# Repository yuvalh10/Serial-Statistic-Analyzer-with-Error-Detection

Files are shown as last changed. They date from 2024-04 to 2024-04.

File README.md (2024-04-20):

# Serial-Statistic-Analyzer-with-Error-Detection

In this VHDL project, our objective is to design a system that receives blocks of data via serial communication and performs statistical analysis, 
including calculations for maximum, minimum, average, and median values. 
Additionally, the system will detect and quantify errors in the communication for each received block of data. 
We'll incorporate pre-existing component files to support the implementation.

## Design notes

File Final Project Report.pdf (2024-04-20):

המחלקה להנדסת התקנים לוגיים חשמל ואלקטרוניקה מתוכנתים, 31551

## דו"ח פרויקט סוף קורס סטטיסטיקה על נתוני בלוקים בתקשורת טורית

מוגש ע"י: יובל המר, 209158518 מוגש ע"י: עידו בן הרוש, 316439116

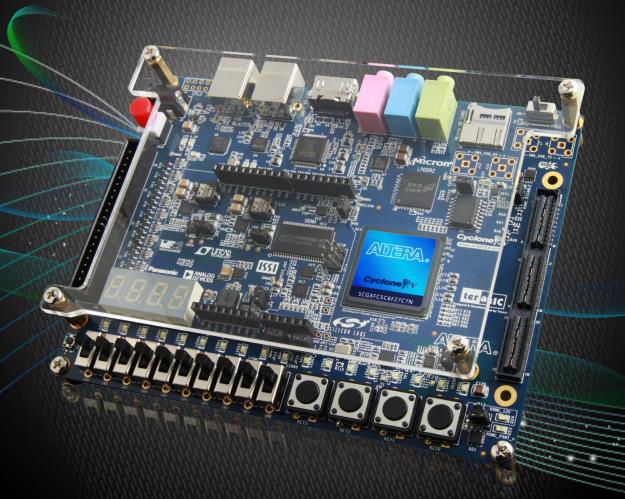
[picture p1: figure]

בהנחיית: ד"ר פאדל טריף

תאריך: 25/03/24

## תוכן עניינים

מבוא: 3 |
פירוט דרישות המערכת4 | :
תיאור מצבי המערכת: 5 |
תהליך תכנון הרכיבים: 6 |
6 | :Serial to Parallel רכיב
תיאור הרכיב: 6 |
סימולציה לרכיב6 | :
דיאגרמת RTL: 8 |
9 | :Main Controller רכיב
תיאור הרכיב: 9 |
דיאגרמת RTL: 10 |
רמה עליונה – Level Top: 11 |
תיאור הרכיב: 11 |
סימולציה לרכיב11 | :
דיאגרמת RTL: 16 |
הקצאת פינים ודו"ח קומפילציה: 17 |
סרטון הדגמת המערכת: 18 |
19 | :SIGNAL-TAP
19 | :SIGNAL-TAP הגדרת
תוצאות אנליזת TAP-SIGNAL20 | :
מצב Ⅰ20 | :
מצב Ⅱ20 | :
מצב Ⅲ22 | :
מצב Ⅳ22 | :
קומפילציה לאחר TAP-SIGNAL23 | :
נספחים: 24 |

## מבוא:

בפרויקט זה, עלינו לתכנן מערכת הקולטת בלוקי נתונים בתקשורת טורית ומחשבת עליהם סטטיסטיקה – מקסימום, מינימום, ממוצע וחציון. בנוסף, המערכת תחשב את מספר השגיאות שהיו בתקשורת הנ"ל עבור כל בלוק נתונים שהתקבל. להלן סכימת בלוקים כללית של המערכת שעלינו לממש:

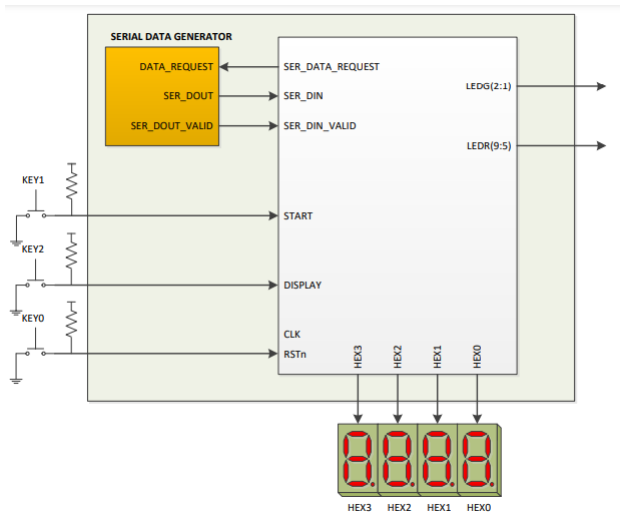
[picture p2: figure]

הבלוק הכתום ידמה את משדר הנתונים הסינכרוני, אשר קיבלנו כרכיב נתון ויהווה חלק מהקושחה הכללית.

## פירוט דרישות המערכת:

.1 המערכת תופעל משעון יחיד של MHz .50 .2 כפתור Reset – עובד בנמוך. .3 המערכת תתעורר במצב Idle. .4 לחיצה ראשונה על הלחצן Start תגרום לבלוק Parallel to Serial להתחיל להוציא בלוק נתונים וכן תעביר את המערכת ממצב Idle למצב קליטה. .5 גודל בלוק נתונים יהיה תמיד 64 נתונים. .6 כל נתון מורכב מ8- סיביות )מספר חיובי בין 0 ל255-( + סיבית זוגיות )סה"כ 9 סיביות לנתון(. .7 כל נתון משודר בצורה טורית. .8 בסיום קליטת 64 הנתונים, המערכת תעבור בצורה אוטומטית למצב חישוב. .9 על המערכת לחשב את הערכים הבאים:

- הערך המקסימלי מתוך 64 הערכים.
- הערך המינימלי מתוך 64 הערכים.
- הערך הממוצע של 64 ערכים.
- החציון של 64 הערכים.
- מספר השגיאות שהגיעו מהמשדר. .10 בחישובים בהם התוצאה יכולה להיות מספר לא שלם, יש לעגל כלפי מטה. .11 בסיום החישוב, המערכת תעבור למצב הצגת הנתונים ותדליק את 2LEDG. .12 במצב הצגת הנתונים יוצג ע"ג התצוגה הערך המקסימלי. לחיצה על Display תגרום להצגת הערך המינימלי, לחיצה נוספת תציג את הממוצע, לחיצה נוספת את החציון ולחיצה נוספת את מספר השגיאות שהיו. לחיצה נוספת תציג מחדש את הערך המקסימלי וחוזר חלילה. .13 לחיצה על Start במצב הצגת הנתונים תחזיר את המערכת למצב Idle. 2LEDG יכבה בשלב זה. .14 לחיצה נוספת על Start אחרי שהמערכת חזרה למצב Idle, תתחיל את התהליך מחדש. .15 1LEDG ידלוק תמיד.
.16 הלדים 9LEDR5-LEDR יסמנו איזו תוצאה מוצגת כרגע על תצוגת ה-Segment.7-.17 כאשר המערכת לא נמצאת במצב הצגת הנתונים, תצוגת ה-Segment7- תהיה כבויה.

## תיאור מצבי המערכת :

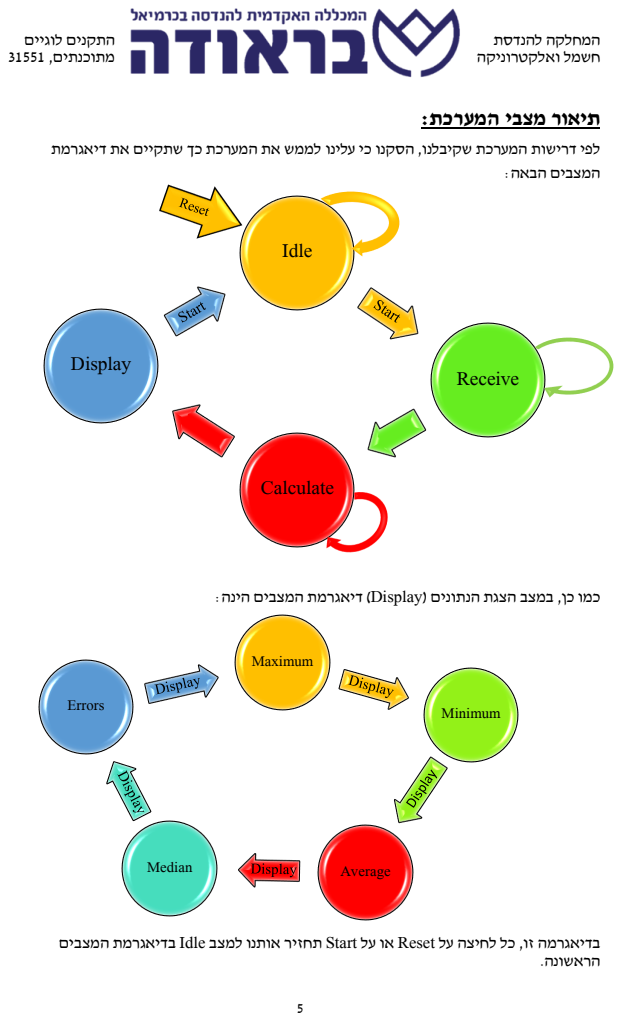
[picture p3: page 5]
המצבים הבאה:; הראשונה.; Idle; Receive; Calculate; Display; Maximum; Minimum; Median; Average; Errors

לפי דרישות המערכת שקיבלנו, הסקנו כי עלינו לממש את המערכת כך שתקיים את דיאגרמת

כמו כן, במצב הצגת הנתונים )Display )דיאגרמת המצבים הינה:

בדיאגרמה זו, כל לחיצה על Reset או על Start תחזיר אותנו למצב Idle בדיאגרמת המצבים

## תהליך תכנון הרכיבים:

בחלק זה נפרט על הרכיבים אשר מימשנו באופן עצמאי בלבד. :Serial to Parallel רכיב
תיאור הרכיב:
רכיב זה ממיר את המידע המתקבל בתקשורת טורית למידע מקבילי אשר עליו ניתן לבצע חישובים וסטטיסטיקות.
בעזרת אוגר הזזה הרכיב קולט את הנתונים הטוריים וממיר אותם למקביליים. כמו כן, הרכיב בודק את תקינות הנתונים בעזרת סיבית הזוגיות שהתקבלה. הנתונים המקביליים מוכנים לעיבוד כאשר מוצא VALID DOUT PAR יהיה '1'.

תיאור סכמתי של הבלוק:

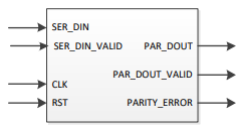
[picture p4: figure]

להלן פירוט הפורטים והמשתנים הגנריים של רכיב זה:

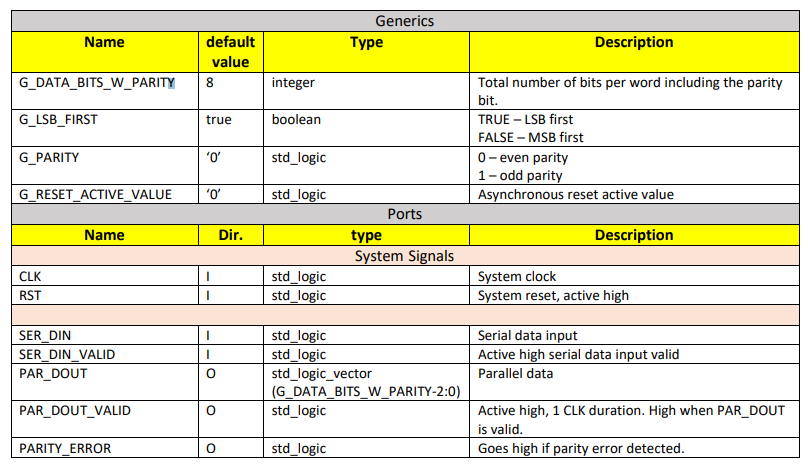
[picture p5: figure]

להלן מימוש רכיב זה: Component Parallel To Serial (https://1drv.ms/u/s!AnQ2VsqUAy-QhfRh5Kb36aPP4mpiXg?e=3cs5c9)

סימולציה לרכיב:
למען בדיקת תקינות רכיב זה, יצרנו קובץ TB וקובץ DO: Serial To Parallel Testbench (https://1drv.ms/u/s!AnQ2VsqUAy-QhfRgW-OdxmMuWwhARA?e=QSDXcm) Serial To Parallel DO (https://1drv.ms/u/s!AnQ2VsqUAy-QhfRXE4jgjZjNv7iw0g?e=mt8uhH)

1 | להלן תוצאות הסימולציה לאחר הרצת ה-TB בתוכנת ה-ModelSim( כניסת LSB
)

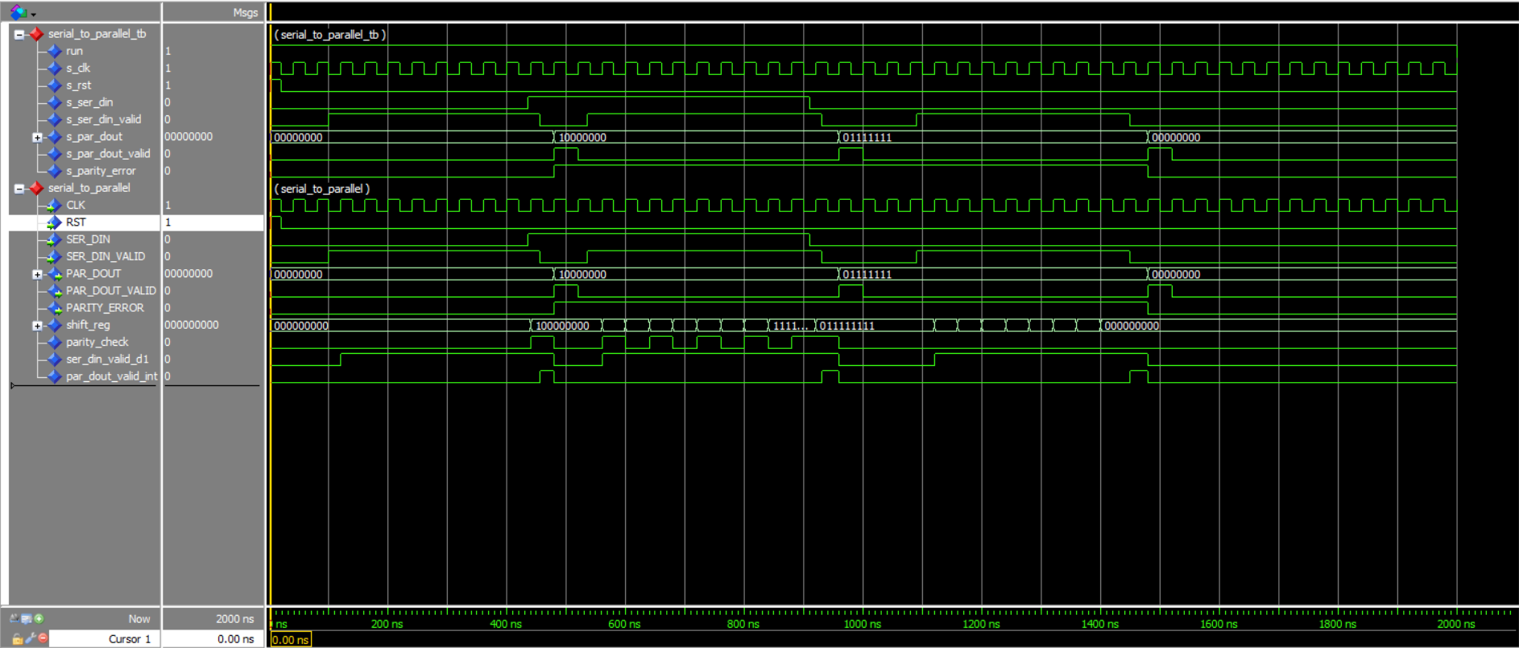
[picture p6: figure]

מצב Ⅰ, כניסת הנתון 11111111 עם סיבית זוגיות 1 )11111111-1(:

ניתן לראות כי הכניסה VALID DIN SER שווה ל-'1' עבור 9 מחזורי שעון מלאים. )ספירת עליית שעון(.
הכניסה DIN SER אשר אחראית על כניסת המידע עולה ל-'1' בעליית שעון הבאה, בעוד שהאות VALID DIN SER יורד ל-'0' למשך 2 מחזורי שעון ועולה חזרה ל-'1'. לאחר מכן, המערכת תתחיל להכניס את המידע לאוגר (Register Shift (כך שסיבית ה-LSB תיכנס ראשונה.
האוגר יתחיל להתמלא במידע ויהיה מוכן ליציאה רק כאשר int_valid_dout_par יהיה '1'. במצב זה הנתונים באוגר יועברו לאות המוצא DOUT_PAR וה-ERROR_PARITY יתעדכן ל-'1'. כלומר הייתה טעות בבדיקת הנתונים.

מצב Ⅱ, כניסת הנתון 00000000 עם סיבית זוגיות 0 )00000000-0(:

הכניסה VALID DIN SER שווה ל-'1' עבור 10 מחזורי שעון מלאים. )ספירת עליית שעון( הכניסה DIN SER נשארת ב-'0' קבוע. המערכת תתחיל להכניס מידע לאוגר כך סיבית ה-LSB תיכנס ראשונה. האוגר יתחיל להתמלא במידע ויהיה מוכן ליציאה רק כאשר int_valid_dout_par יהיה '1'. במצב זה הנתונים באוגר יועברו לאות המוצא DOUT_PAR וה-ERROR_PARITY יתעדכן ל-'0'. כלומר לא הייתה שגיאה בקליטת הנתונים.

1
עבור כניסת MSB תוצאות הסימולציה יהיו זהות פרט לאופן כניסת המידע לאוגר ההזזה )הכנסה לימין לשמאל(

דיאגרמת RTL:

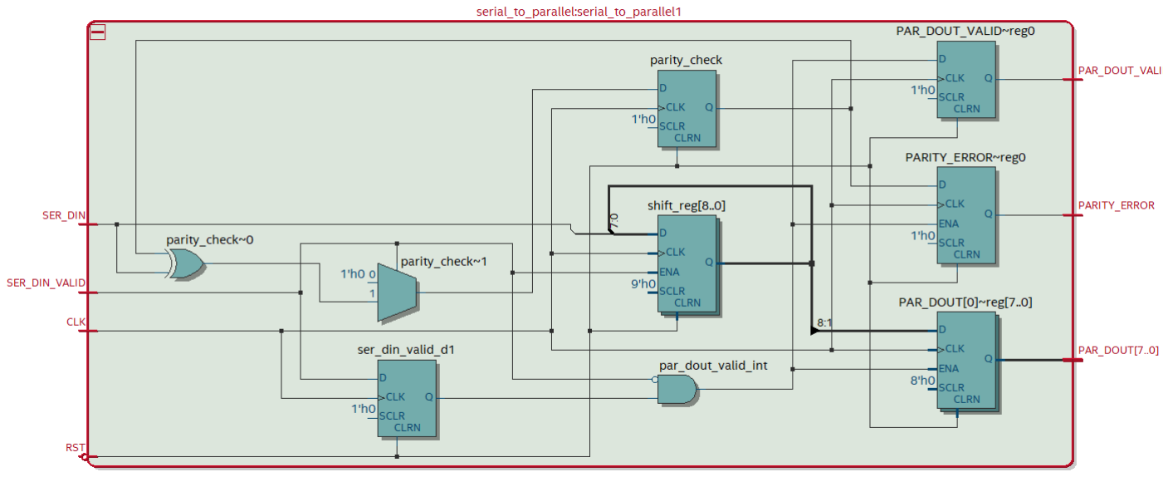
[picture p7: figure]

Main Controller רכיב ² :
תיאור הרכיב:
רכיב זה אחראי על מעבר בין מכונת מצבים שתוארה קודם לכן. הרכיב אחראי ליצירת אות לבקשת המידע (Request Data(. כמו כן, הרכיב אחראי למיון הנתונים לפי מיון בועות (sort Bubble (וחישוב הסטטיסטיקות להצגה. בנוסף, במוצא הרכיב נקבל את האותות הבאים להצגת הנתונים: RESULT – הסטטיסטיקה המוצגת )מקסימום, מינימום, ממוצע, חציון או שגיאות(. READY_RESULT – משמעותו שהנתונים מוכנים לתצוגה למשתמש. TYPE_RESULT – אחראי על תצוגת סוג הסטטיסטיקה המוצגת )מחובר ללדים האדומים ברמה העליונה(

תיאור סכמתי של הבלוק:

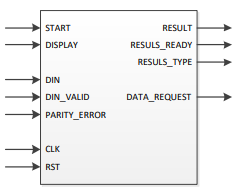
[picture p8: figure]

להלן פירוט הפורטים והמשתנים הגנריים של רכיב זה:

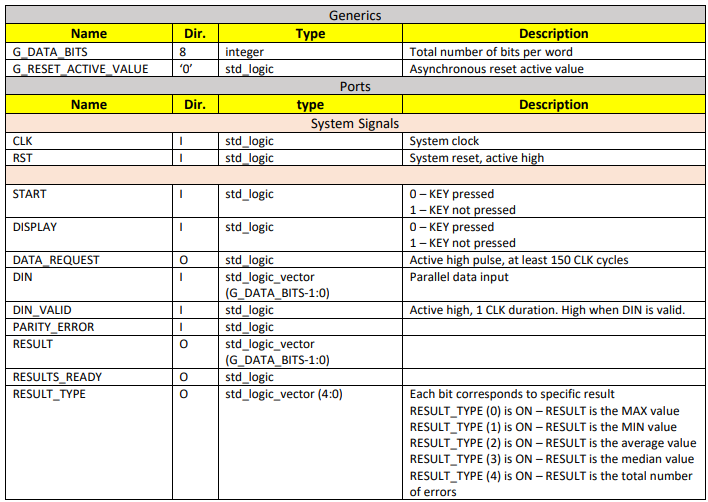
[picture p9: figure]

להלן מימוש רכיב זה: Component Controller Main (https://1drv.ms/u/s!AnQ2VsqUAy-QhfRi5hOepWznz8q90g?e=I6kWVU)

2
בלוק זה ייבדק במהלך ביצוע הסימולציה הכללית הנתונה לרמה העליונה.

3: | דיאגרמת RTL

3

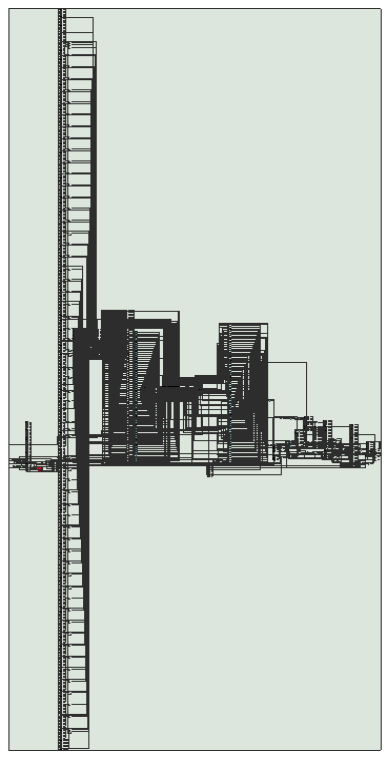
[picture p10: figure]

במהלך בדיקת מכונת המצבים ברכיב, זה נוכחנו לגלות כי היא לא מומשה כמצופה, אלא בעזרת רכיבים חומרתיים בלבד. ייתכן כי עובדה זו גלומה בכך שהמערכת עשתה אופטימיזציה והצליחה למצוא דרך לממש את מכונת המצבים )הנחשבת בזבזנית( בעזרת ר כיבים פשוטים יותר.

רמה עליונה – Level Top:
תיאור הרכיב:
לאחר שמימשנו את הבקר הראשי (Controller Main (ואת ממיר הנתונים (Parallel To Serial (תוך שימוש בשאר הרכיבים שנתונים לנו בפרויקט זה, בנינו את הרכיב calc_Statistics הנחשב כישות רמה עליונה (entity level Top (ומתכלל בין כלל הרכיבים אל ה-"עולם החיצון."

כמו כן, ישות זו מקשרת בין הפורטים הרלוונטיים בין כלל הרכיבים על מנת לקבל את התוצאה הרצויה.

להלן פירוט הפורטים של רכיב זה:

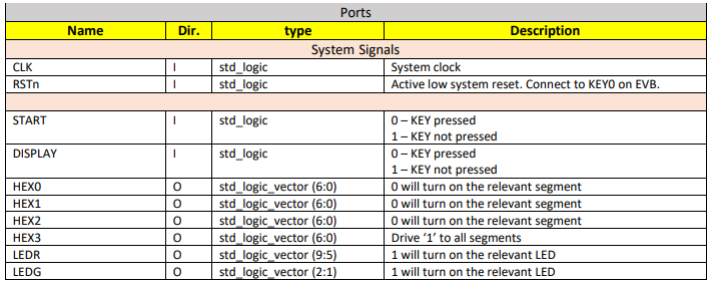
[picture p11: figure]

להלן מימוש רכיב זה: Level Top calc Statistics (https://1drv.ms/u/s!AnQ2VsqUAy-QhfRfBacUU58DXrMCdQ?e=kP4u3r)

סימולציה לרכיב:
למען בדיקת תקינות רכיב זה, קיבלנו קובץ TB ייעודי ומספר וקבצי DO: Statistics calc Testbench (https://1drv.ms/u/s!AnQ2VsqUAy-QhfReSqyLuajTX-yCDA?e=2TuPq3)
DO components all Compile (https://1drv.ms/u/s!AnQ2VsqUAy-QhfRdWf5gRi4n26bK4Q?e=eJn6oB) – קובץ קומפילציה לכלל הרכיבים במערכת. DO all Run (https://1drv.ms/u/s!AnQ2VsqUAy-QhfRbAB2FfqaXUPI_kg?e=yptIfv) – קובץ הרצת הסימולציה.

להלן תוצאות הסימולציה לאחר הרצת ה-TB בתוכנת ה- ModelSim) Controller Main(:

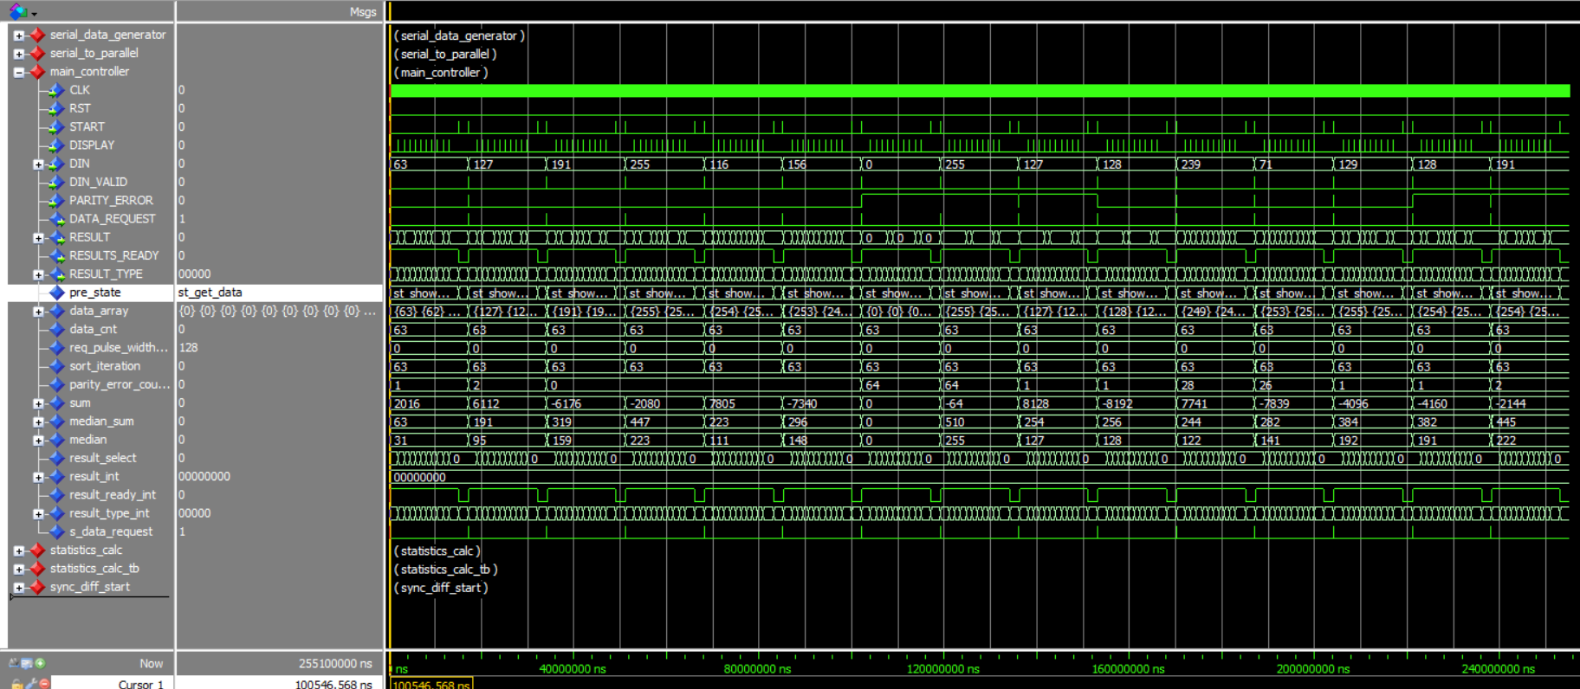
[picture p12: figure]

נתרכז בקבלת הנתון הראשון:

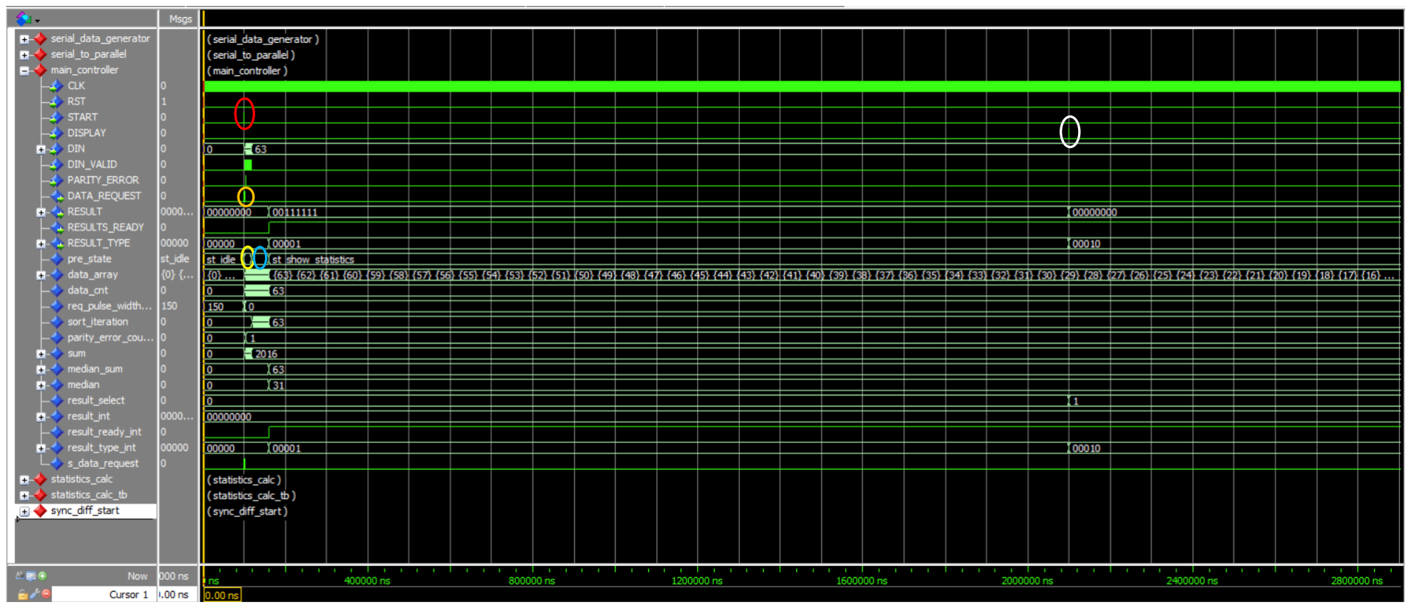
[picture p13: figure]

ניתן לראות כי בתחילת הרצת הסימולציה המערכת מתעוררת במצב Idle כנדרש. לאחר מכן, לאחר לחיצה על Start( מסומן באדום( תיתן פקודה לאות REQUEST DATA לקבל '1' )מסומן בכתום( והמערכת עוברת למצב data Get( מסומן בצהוב(. לאחר מכן נעבור למצב של מיון הנתונים )מסומן בכחול(.
רק לאחר שאות המוצא READY RESULTS עולה ל1- אנו נכנסים למצב של הצגת הנתונים כאשר הנתון הראשון שאנו מציגים הינו הערך המקסימלי. לחיצה על לחצן ה-Display( מסומן בלבן( תעביר אותנו להצגת הערך המינימלי כנדרש.

להלן תוצאות הסימולציה לאחר הרצת ה-TB בתוכנת ה- ModelSim) calc Statistics(:

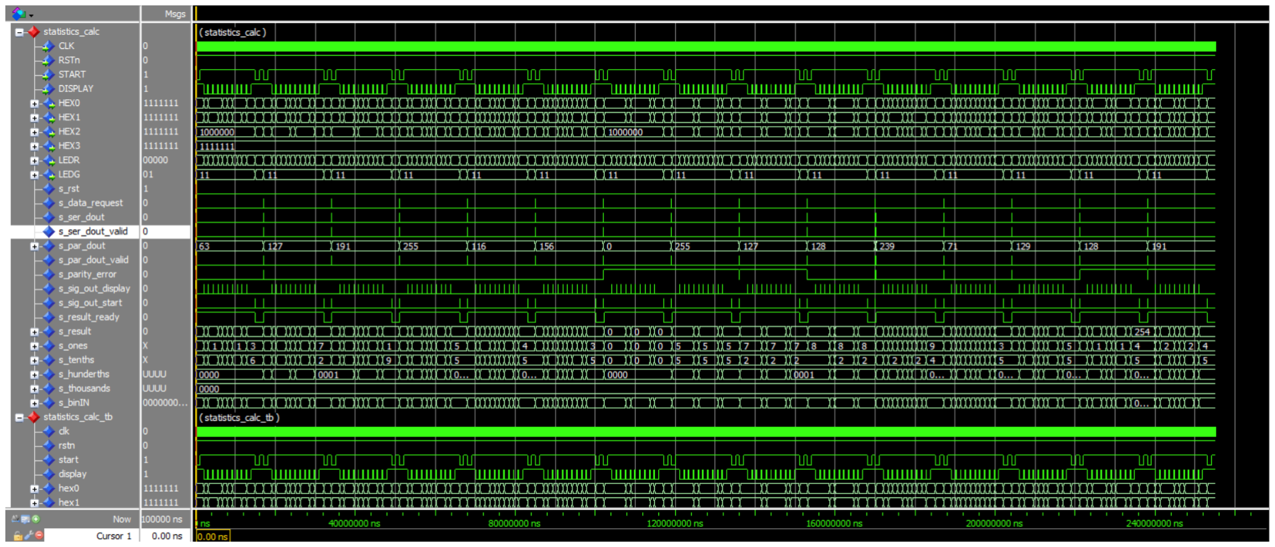
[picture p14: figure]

נתרכז בקבלת הנתון הראשון:

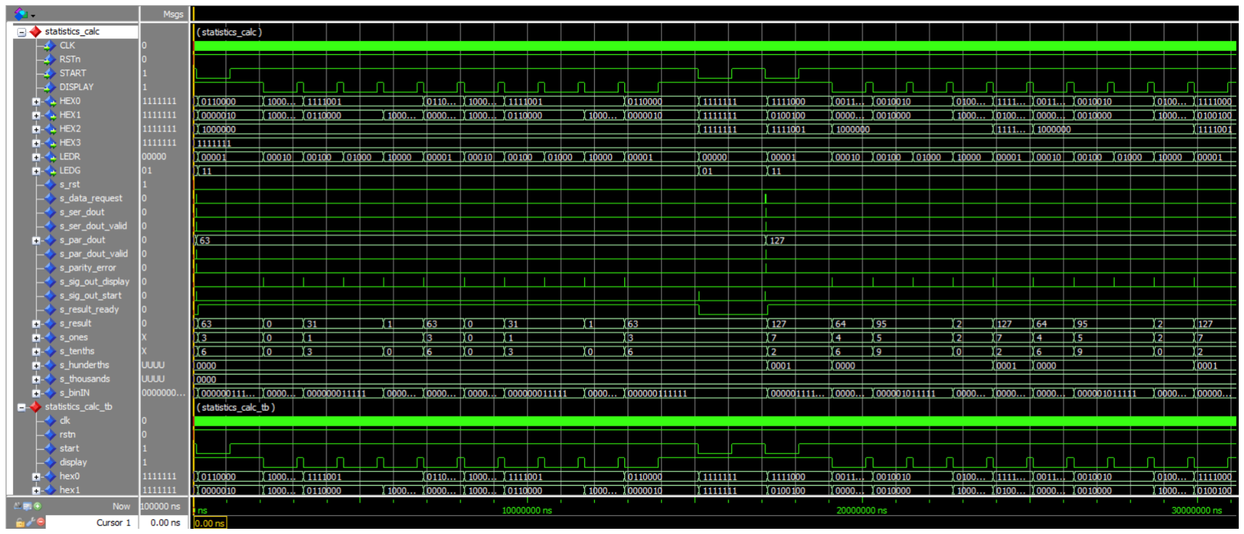
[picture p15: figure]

ניתן לראות כי כאשר לחצן ה-Start עובד בנמוך המערכת מתחילה את פעולתה. בנוסף, עבור לחיצה על לחצן ה-Display( עובד בנמוך( ניתן לראות המעברים בין הסטטיסטיקות שחושבו על הנתונים.
את המעברים הנ"ל ניתן לראות בשינוי התוצאות בסיגנל result_s ובשינוי ה-LEDR שדולק בהתאם לסטטיסטיקה המוצגת.
כמו כן, לחיצה נוספת על Start תוריד את הסיגנל ready_result_s ל-'0' ובכך תינתן פקודה לעבור להציג את הסטטיסטיקות על הנתון הבא. הצגת הנתונים הבאה תתאפשר רק לאחר שהסיגנל ready_result_s עלה ל'1'.

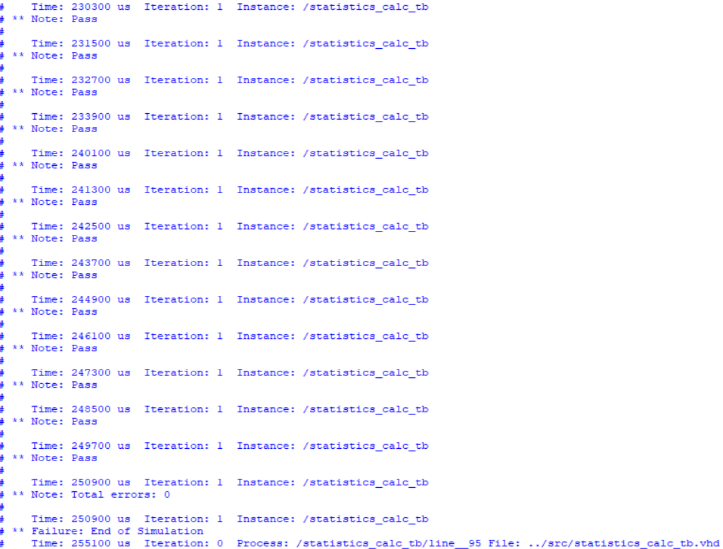
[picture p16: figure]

בנוסף, הופק עבורנו דו"ח מה-TB בו השתמשנו על מנת לזהות שגיאות בפעולת המערכת:

ניתן לראות כי המערכת שבנינו עברה את כל הבדיקות הנדרשות ב-TB זה וסימולציית המערכת הושלמה בהצלחה.

דיאגרמת RTL:

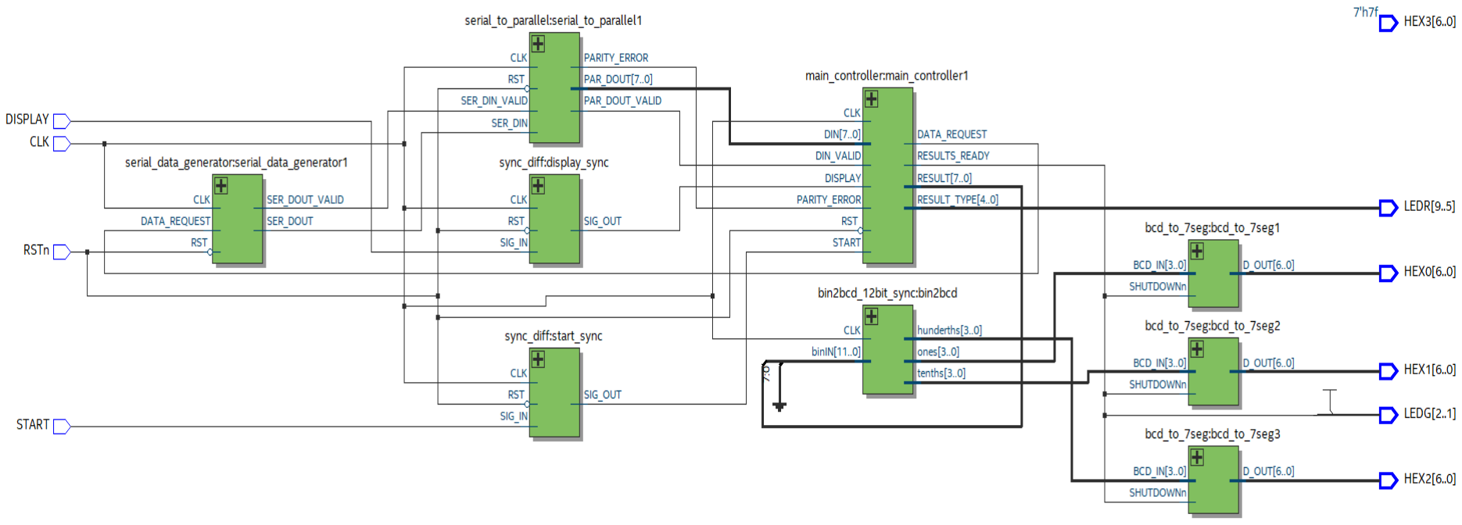
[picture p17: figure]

## הקצאת פינים ודו"ח קומפילציה :

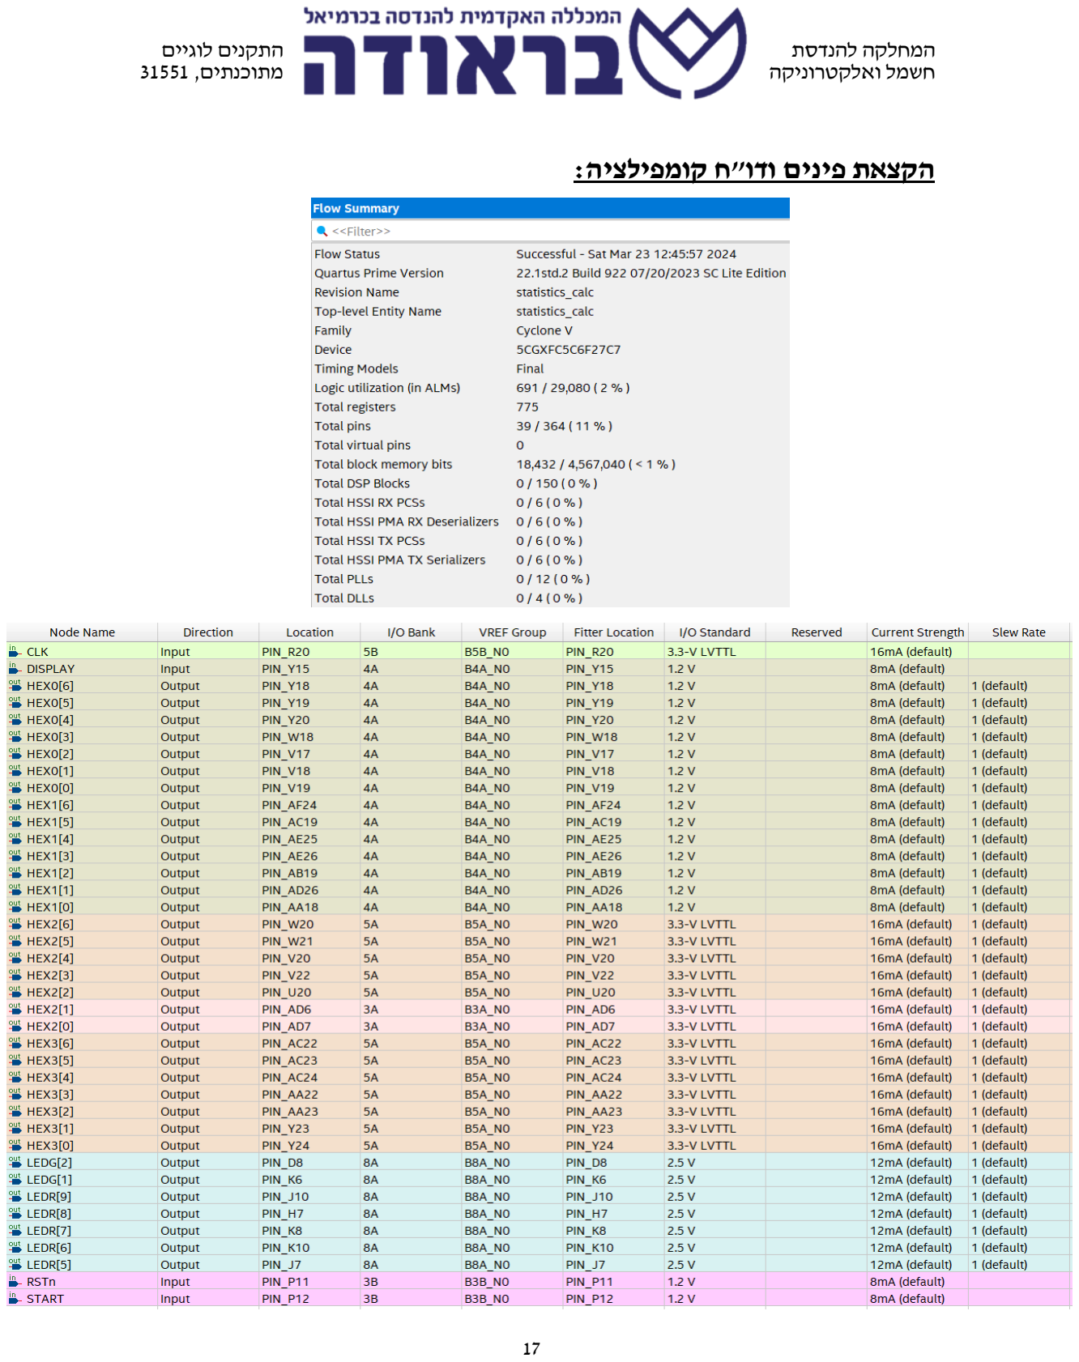
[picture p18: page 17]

## סרטון הדגמת המערכת:

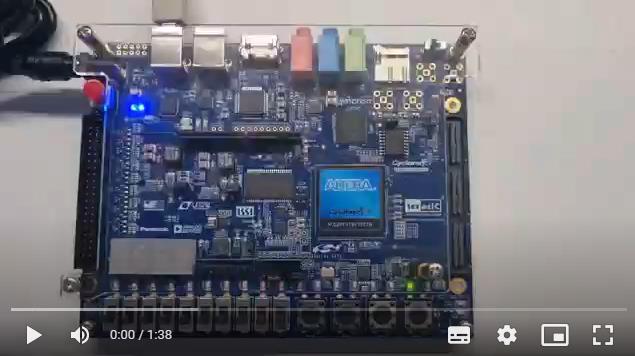
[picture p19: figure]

## :SIGNAL-TAP

:SIGNAL-TAP הגדרת
במטרה להשתמש ב-Tap-Signal יצרנו קובץ חדש מסוג STP והגדרנו את ה-Tap-Signal באופן הבא:

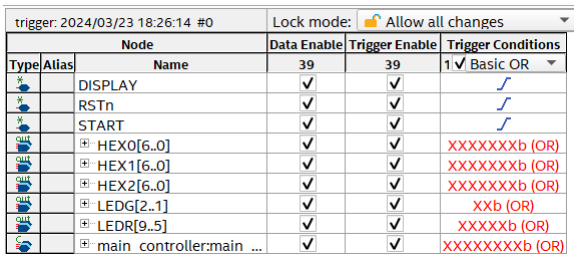
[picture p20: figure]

בכדי לראות בתוכנת הקוורטוס שהמערכת עובדת כראוי, הוספנו את לחצני ה- Start ,Reset ,Display מכיוון שהם משפיעים על מעבר המערכת ממצב למצב וביכולתו של המשתמש להיות בבקרה על כך. נוסיף גם את תצוגות ה-Segment7- בכדי לראות את השינויים שבתצוגה. נוסיף גם את LEDG ו-LEDR בכדי לראות את השינויים המתבצעים בהם במעבר ממצב אחד למשנהו.
בנוסף, נרצה לוודא שהתוצאות המוצגות ברכיב אכן נכונות, לשם כך נוסיף את אות ה-RESULT. בכדי לראות את השינויים בין מצב אחד לאחר, נדרוש שהאנליזה תתרחש בעליית הלחצנים שהגדרנו תוך לוגיקת OR בין הדרבונים הנ"ל.

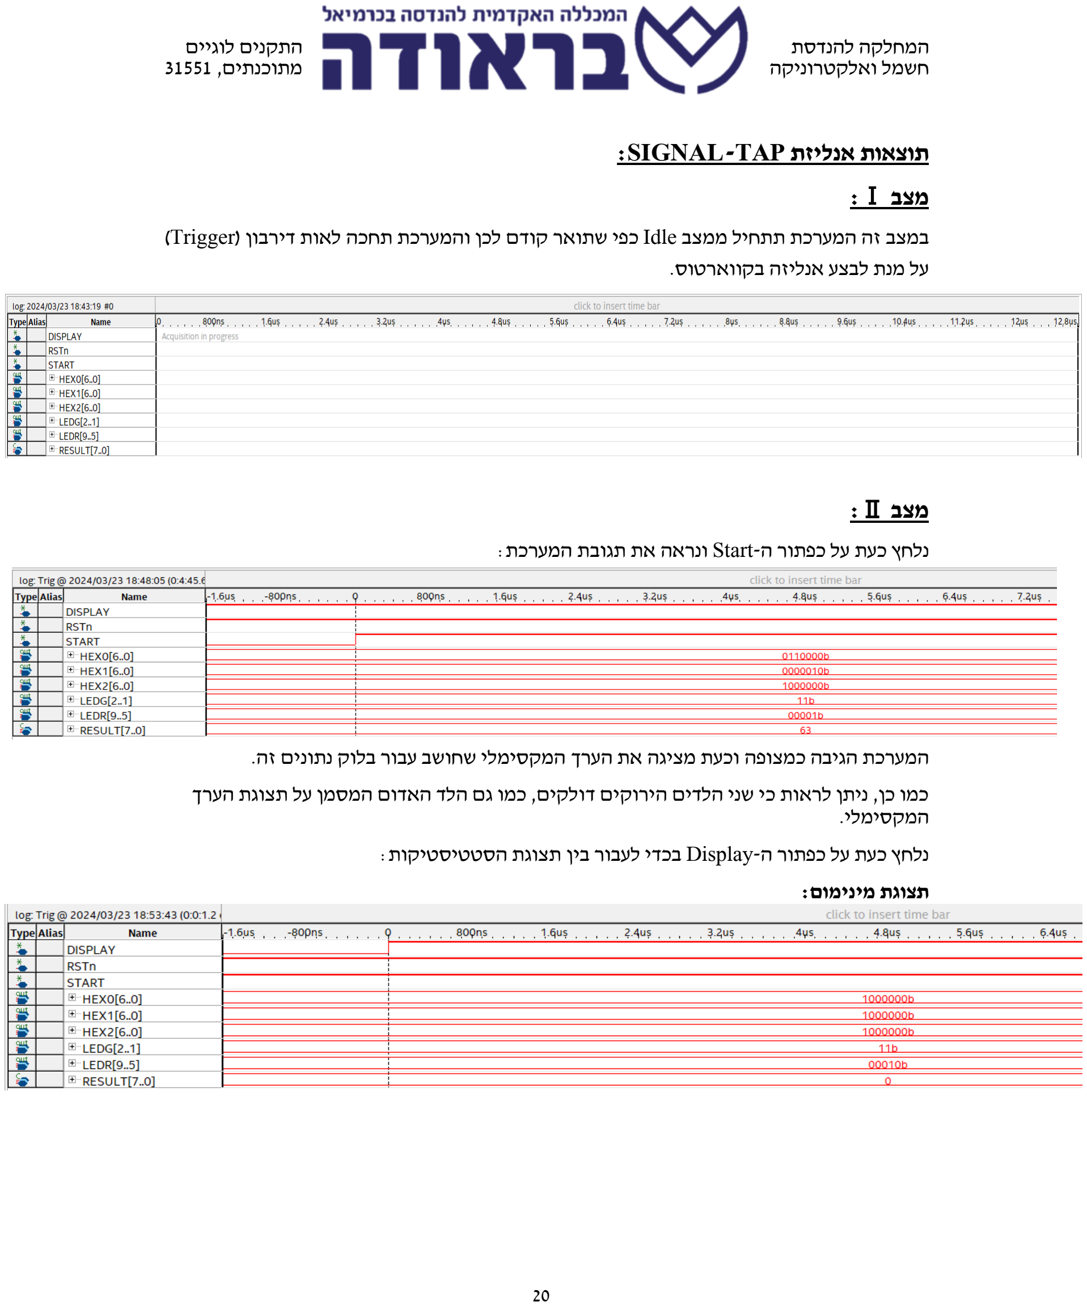
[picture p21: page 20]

תוצאות אנליזת TAP-SIGNAL:
מצב Ⅰ:

במצב זה המערכת תתחיל ממצב Idle כפי שתואר קודם לכן והמערכת תחכה לאות דירבון (Trigger( על מנת לבצע אנליזה בקווארטוס.

מצב Ⅱ:

נלחץ כעת על כפתור ה-Start ונראה את תגובת המערכת:

המערכת הגיבה כמצופה וכעת מציגה את הערך המקסימלי שחושב עבור בלוק נתונים זה. כמו כן, ניתן לראות כי שני הלדים הירוקים דולקים, כמו גם הלד האדום המסמן על תצוגת הערך המקסימלי.
נלחץ כעת על כפתור ה-Display בכדי לעבור בין תצוגת הסטטיסטיקות: תצוגת מינימום:

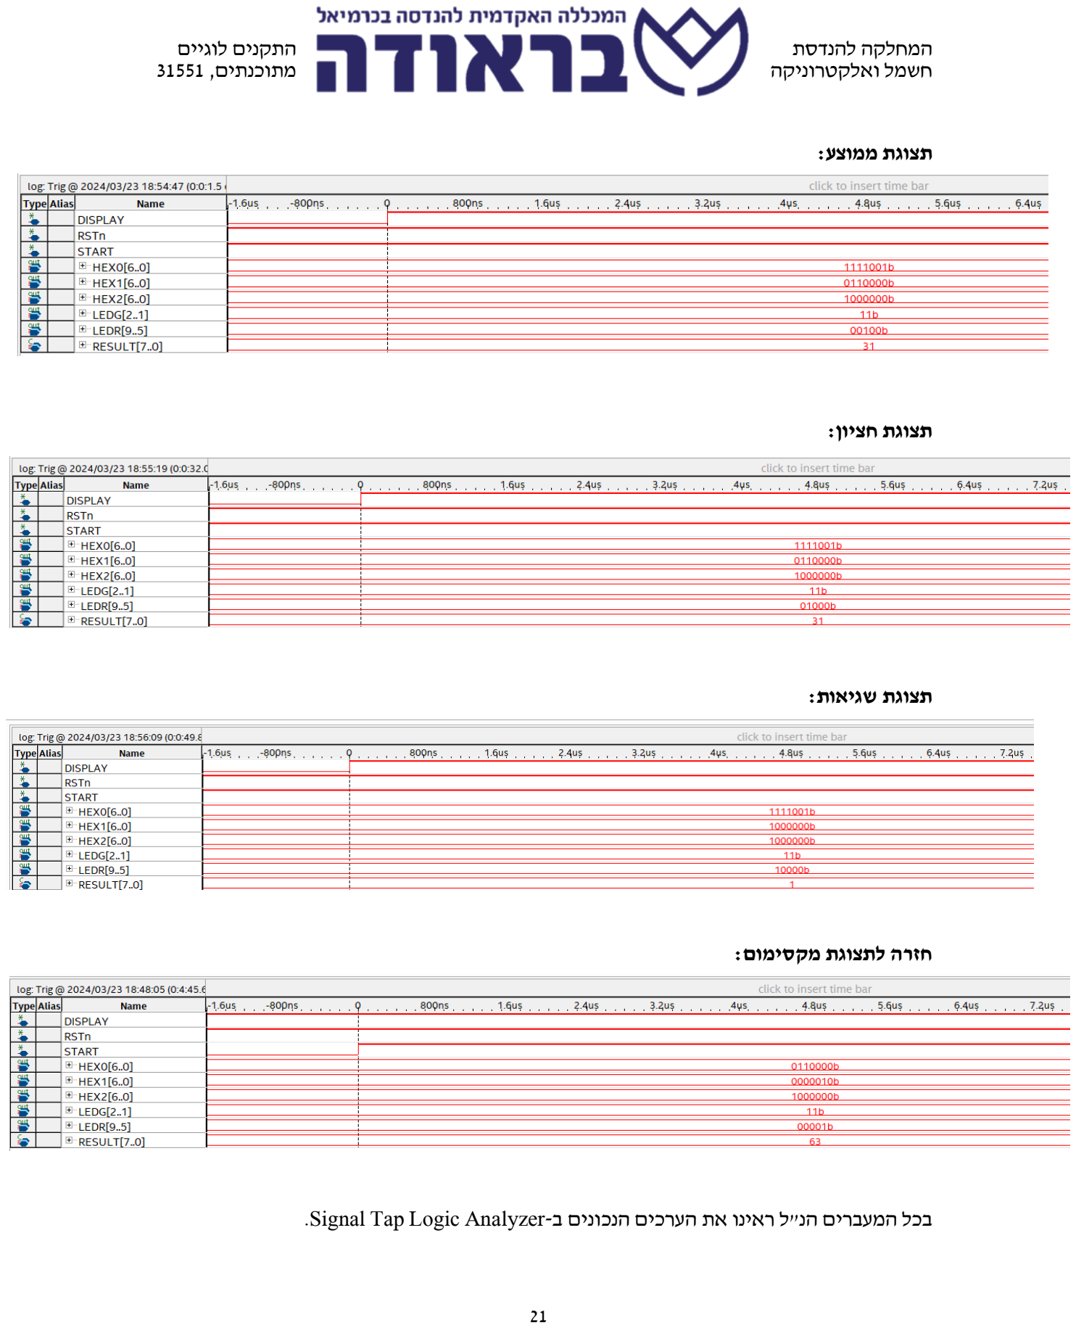
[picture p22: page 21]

תצוגת ממוצע:

תצוגת חציון:

תצוגת שגיאות:

חזרה לתצוגת מקסימום:

בכל המעברים הנ"ל ראינו את הערכים הנכונים ב-Analyzer Logic Tap Signal.

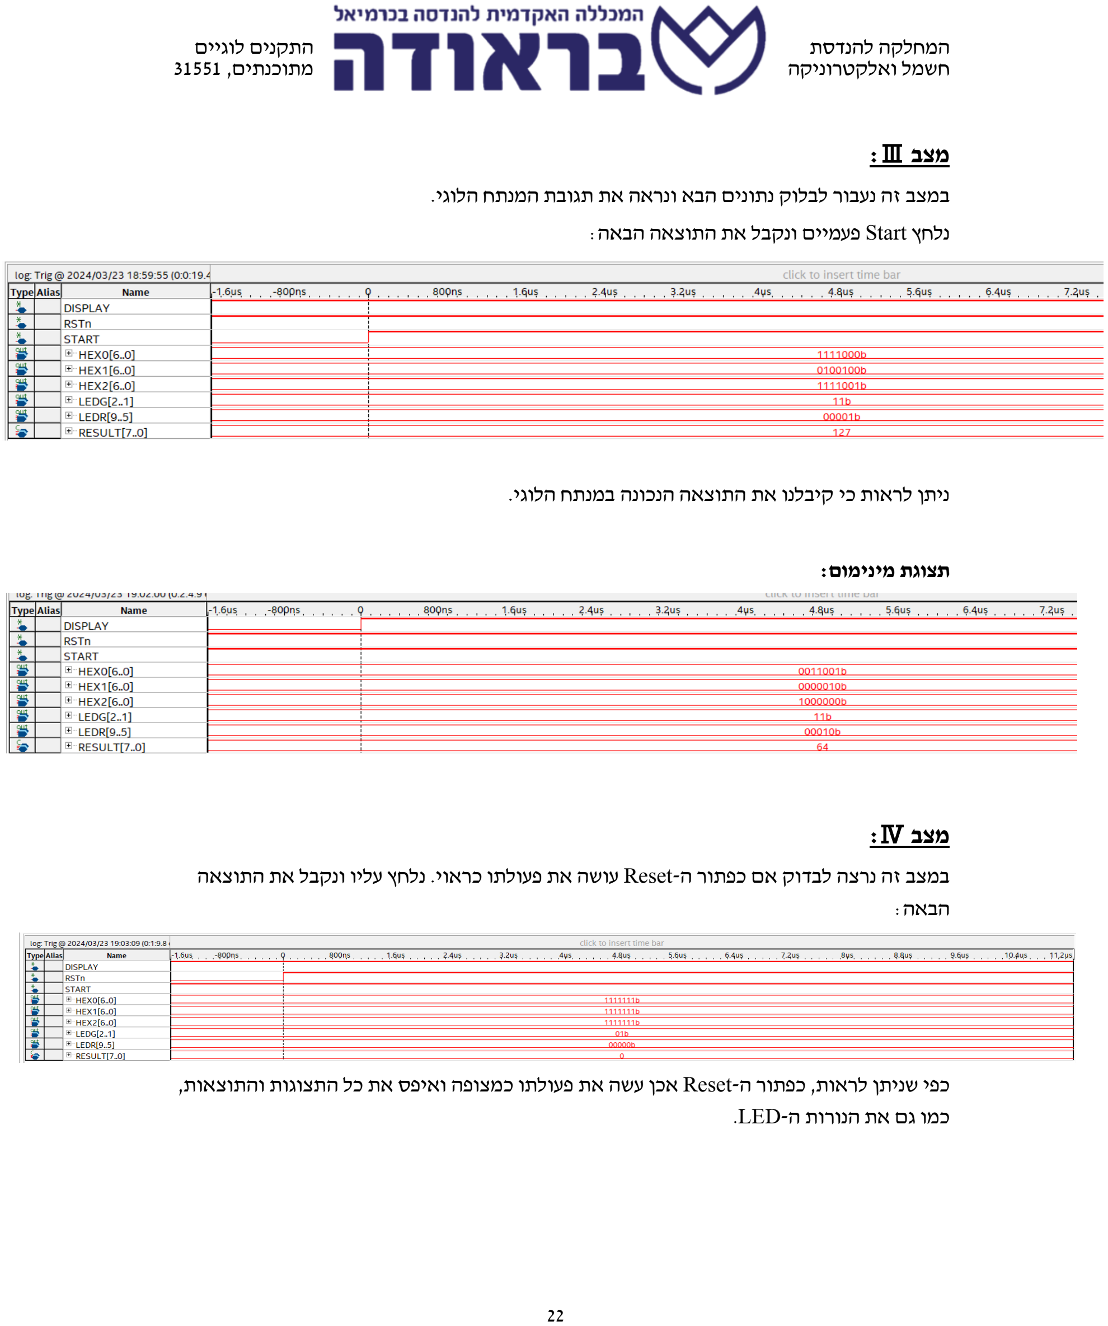
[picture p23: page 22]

מצב Ⅲ:

במצב זה נעבור לבלוק נתונים הבא ונראה את תגובת המנתח הלוגי. נלחץ Start פעמיים ונקבל את התוצאה הבאה:

ניתן לראות כי קיבלנו את התוצאה הנכונה במנתח הלוגי.

תצוגת מינימום:

מצב Ⅳ:

במצב זה נרצה לבדוק אם כפתור ה-Reset עושה את פעולתו כראוי. נלחץ עליו ונקבל את התוצאה הבאה:

כפי שניתן לראות, כפתור ה-Reset אכן עשה את פעולתו כמצופה ואיפס את כל התצוגות והתוצאות, כמו גם את הנורות ה-LED.

קומפילציה לאחר TAP-SIGNAL:

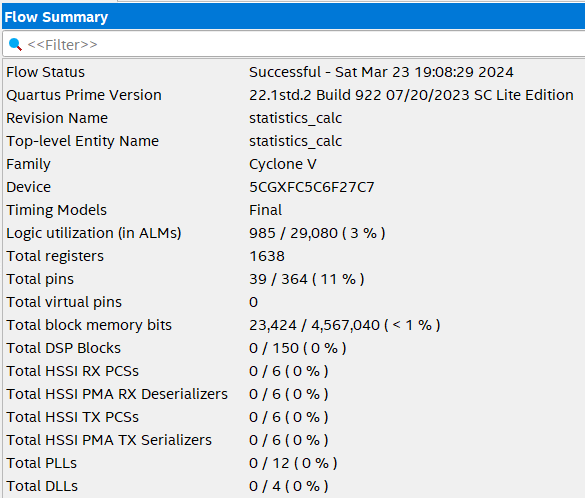
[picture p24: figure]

כפי שניתן לראות, לאחר שימוש ב-TAP-SIGNAL המערכת צרכה יותר משאבים על מנת לבצע את הניתוח הנדרש.

## נספחים:

1. Serial Data Generator (https://1drv.ms/u/s!AnQ2VsqUAy-QhfQ45B-jDy8r7JzWfw?e=iRySUG)
2. Synchronizer & differentiator (https://1drv.ms/u/s!AnQ2VsqUAy-QhfQ5kB8xpisSHdyg4Q?e=QZn502)
3. Binary to BCD 12 BITS synchronizer (https://1drv.ms/u/s!AnQ2VsqUAy-QhfQ79pOUBg2QNdfgpw?e=VX53Rr)
4. BCD to 7-segment (https://1drv.ms/u/s!AnQ2VsqUAy-QhfQ6qCeCzscdYTCUJg?e=Zu8lWJ)
5. Data rom (https://1drv.ms/u/s!AnQ2VsqUAy-QhfQ9thhr2nwbAK7A8g?e=FjaP25)
6. Final results (https://1drv.ms/t/s!AnQ2VsqUAy-QhfQ-bURVwkJIB1LsBw?e=wdMcMo)

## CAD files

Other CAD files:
Code Files/par/SIGNALTAP.stp

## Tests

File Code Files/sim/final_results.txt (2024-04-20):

Max     Min     Ave     Med     Err
63	0	31	31	1
127	64	95	95	2
191	128	159	159	0
255	192	223	223	0
254	7	121	111	0
253	10	141	148	0
0	0	0	0	64
255	255	255	255	64
127	127	127	127	1
128	128	128	128	1
249	1	120	122	28
253	15	133	141	26
255	129	192	192	1
254	128	191	191	1
254	191	222	222	2
